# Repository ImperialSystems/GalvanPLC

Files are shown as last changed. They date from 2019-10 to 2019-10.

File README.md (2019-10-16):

# GalvanPLC
Galvan PLC es una adaptación de la plataforma Arduino al ámbito industrial, dicho de forma más clara es una imitación de los PLC. El hardware es completamente abierto y está bajo licencia GPL V2. El PCB fue diseñado en KiCAD con solo una capa y pensado para que pueda montarse tanto de forma casera como de forma profesional. Cuenta con 4 salidas digitales del tipo relay, 3 salidas analógicas de 0-5V, 2 entradas analógicas de 10V, 2 entradas analógicas de 4-20mA y 5 entradas digitales de 24V. Puede alimentarse entre 8VDC y 30VDC. Posee conexión USB y comunicación I2C. Es compatible con Soapbox Snap, OpenPLC, LDmicro y Arduino IDE, entre otros.

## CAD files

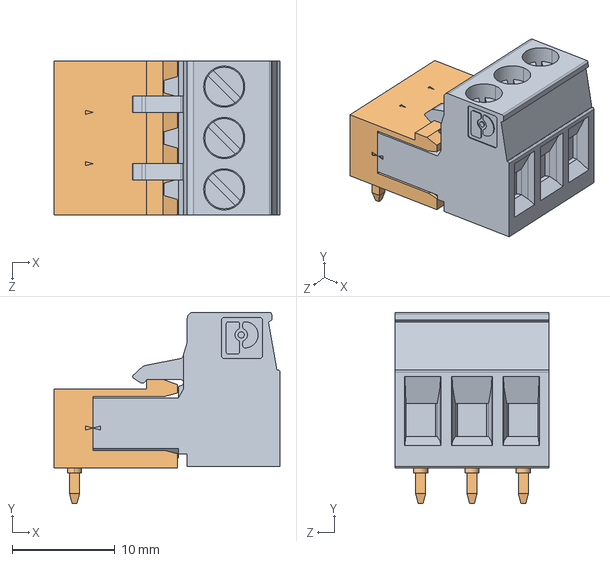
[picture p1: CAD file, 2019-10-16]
v0.0.1/PCB/STEP/MSTB 2,5_3_ST_1754465 + MSTB 2,5_ 3_G_1754452 (Phoenix Contact).STEP
22.0 x 18.6 x 15.0 mm

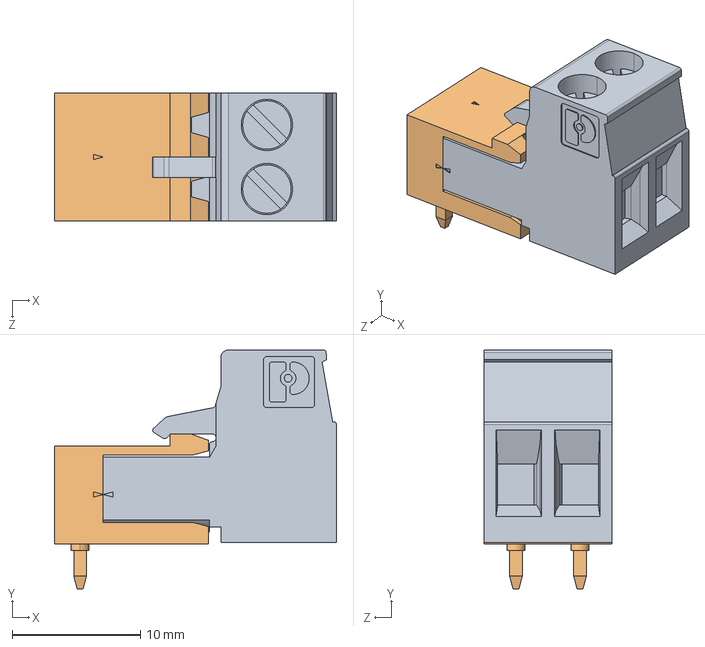
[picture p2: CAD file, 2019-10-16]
v0.0.1/PCB/STEP/MSTB 2,5_2_ST_1754449 + MSTB 2,5_ 2_G_1754436 (Phoenix Contact).STEP
22.0 x 18.6 x 10.0 mm

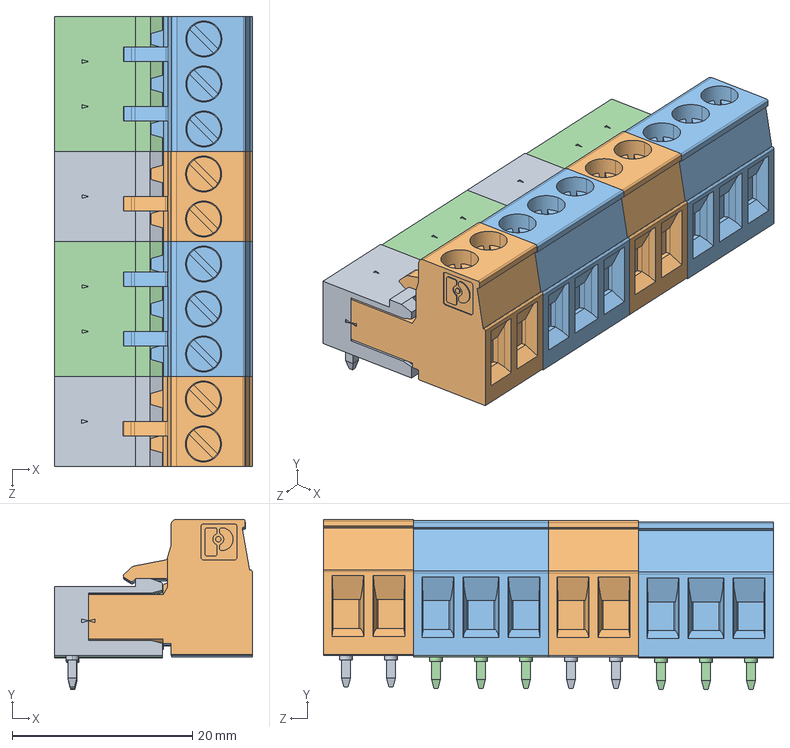
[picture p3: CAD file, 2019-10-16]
v0.0.1/PCB/STEP/MSTB 2,5_10_ST_1754465 + MSTB 2,5_ 3_G_1754452 (Phoenix Contact).STEP
22.0 x 18.9 x 50.0 mm
MSTB 2,5_2_ST_1754449 + MSTB 2,5_ 2_G_1754436 (Phoenix Contact).step
MSTB 2,5_3_ST_1754465 + MSTB 2,5_ 3_G_1754452 (Phoenix Contact).step
MSTB 2,5_2_ST_1754449 + MSTB 2,5_ 2_G_1754436 (Phoenix Contact).step.STEP
MSTB 2,5_3_ST_1754465 + MSTB 2,5_ 3_G_1754452 (Phoenix Contact).step.STEP

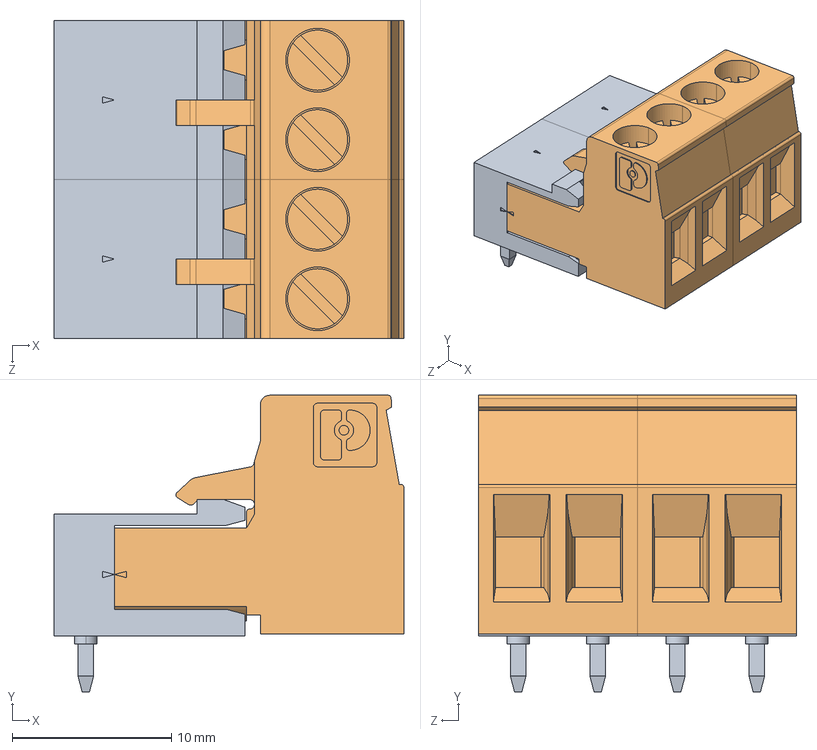
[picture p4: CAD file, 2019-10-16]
v0.0.1/PCB/STEP/MSTB 2,5_4_ST_1754465 + MSTB 2,5_ 3_G_1754452 (Phoenix Contact).STEP
22.0 x 18.6 x 20.0 mm
MSTB 2,5_2_ST_1754449 + MSTB 2,5_ 2_G_1754436 (Phoenix Contact).step x 2

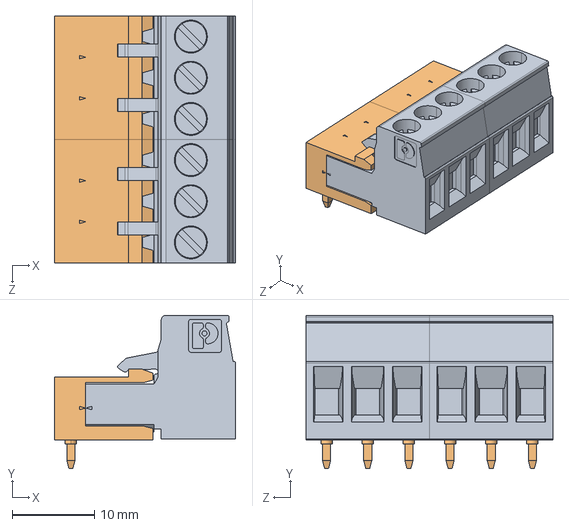
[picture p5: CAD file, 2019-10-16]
v0.0.1/PCB/STEP/MSTB 2,5_6_ST_1754465 + MSTB 2,5_ 3_G_1754452 (Phoenix Contact).STEP
22.0 x 18.6 x 30.0 mm
MSTB 2,5_3_ST_1754465 + MSTB 2,5_ 3_G_1754452 (Phoenix Contact).step x 2

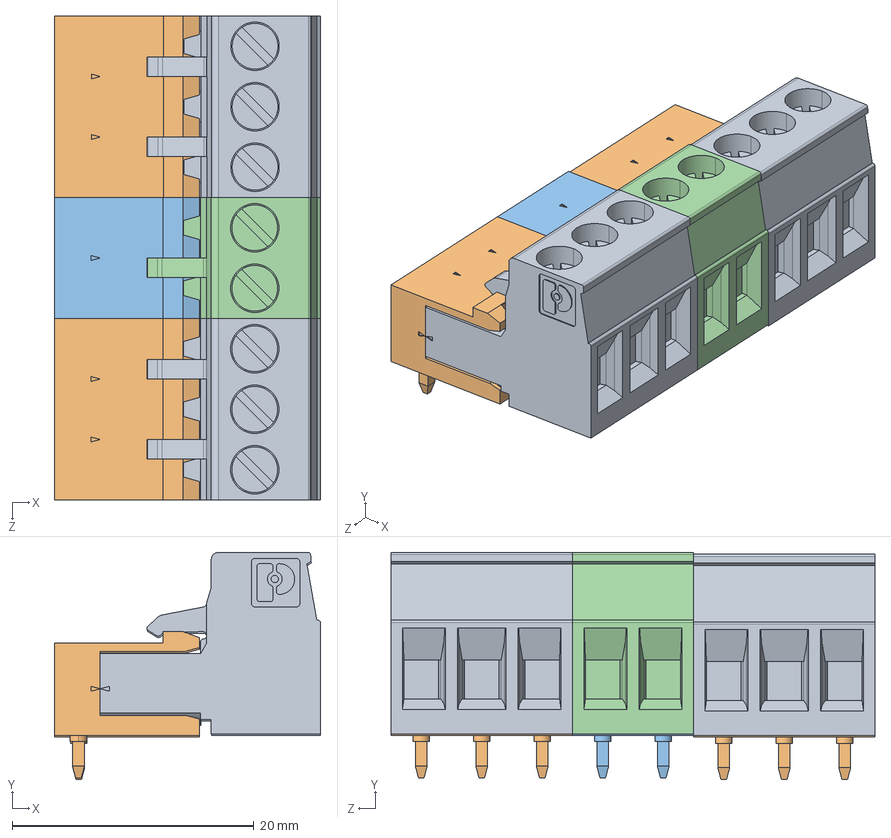
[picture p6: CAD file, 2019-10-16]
v0.0.1/PCB/STEP/MSTB 2,5_8_ST_1754465 + MSTB 2,5_ 3_G_1754452 (Phoenix Contact).STEP
22.0 x 18.8 x 40.0 mm
MSTB 2,5_3_ST_1754465 + MSTB 2,5_ 3_G_1754452 (Phoenix Contact).step
MSTB 2,5_2_ST_1754449 + MSTB 2,5_ 2_G_1754436 (Phoenix Contact).step.STEP
MSTB 2,5_3_ST_1754465 + MSTB 2,5_ 3_G_1754452 (Phoenix Contact).step.STEP

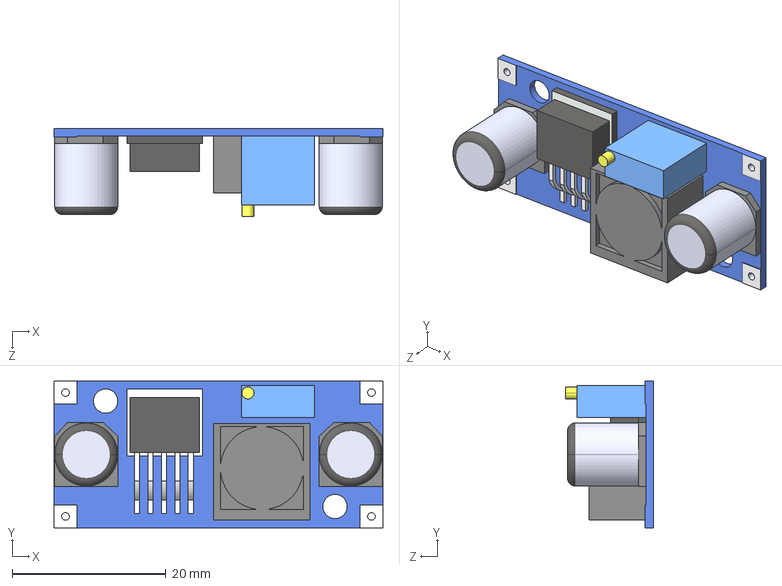
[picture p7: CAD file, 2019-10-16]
v0.0.1/PCB/STEP/stepdown voltage converter.STEP
42.9 x 19.1 x 11.5 mm

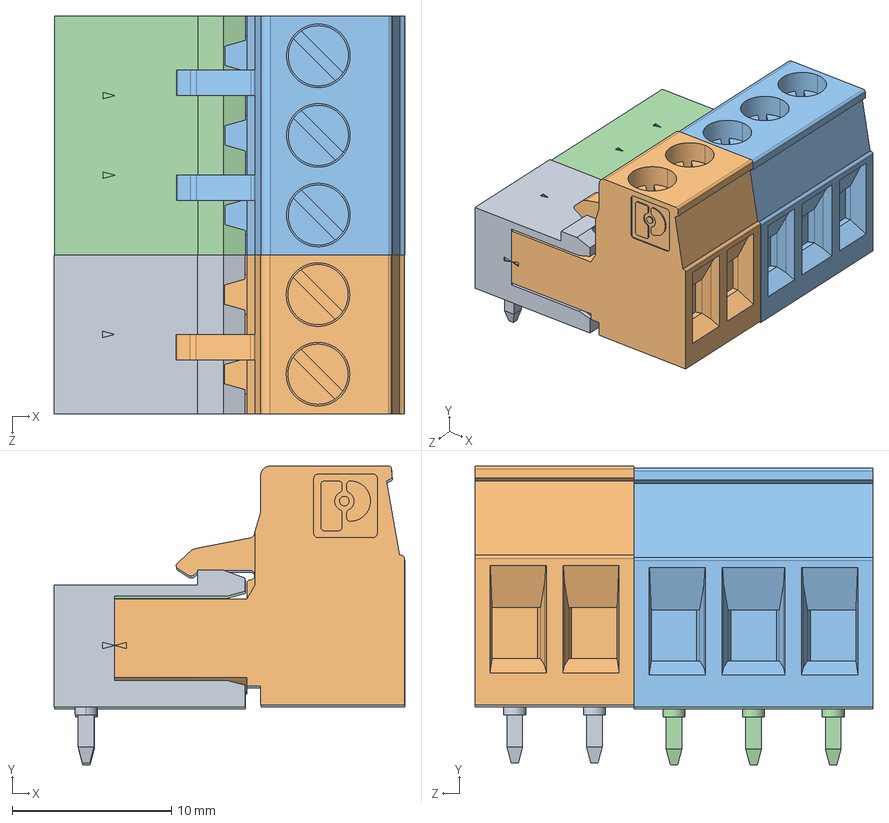
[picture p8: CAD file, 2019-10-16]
v0.0.1/PCB/STEP/MSTB 2,5_5_ST_1754449 + MSTB 2,5_ 2_G_1754436 (Phoenix Contact).STEP
22.0 x 18.8 x 25.0 mm
MSTB 2,5_2_ST_1754449 + MSTB 2,5_ 2_G_1754436 (Phoenix Contact).step
MSTB 2,5_3_ST_1754465 + MSTB 2,5_ 3_G_1754452 (Phoenix Contact).step

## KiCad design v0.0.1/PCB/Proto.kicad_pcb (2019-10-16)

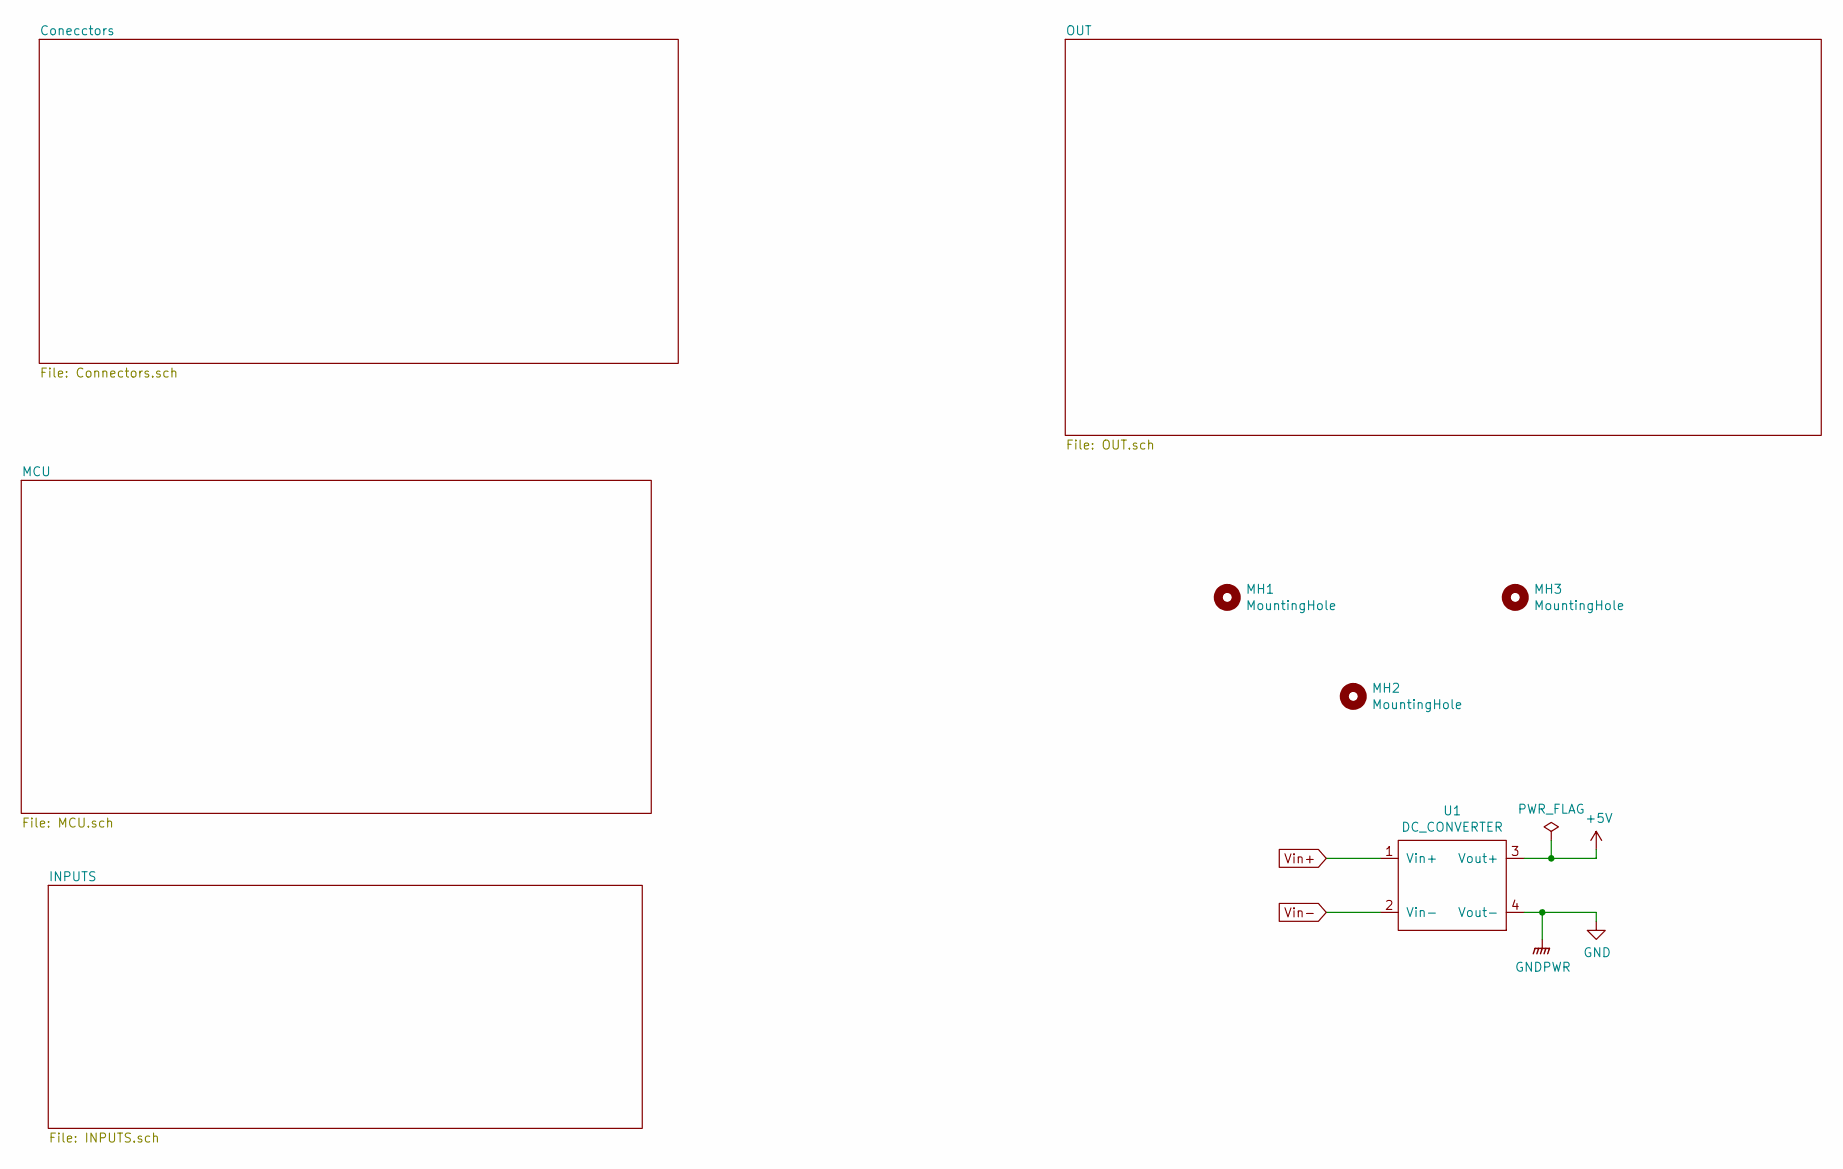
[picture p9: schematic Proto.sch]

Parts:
MH1, MH2, MH3: MountingHole; MountingHole_5mm
U1: DC_CONVERTER; Module_LM2596

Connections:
+5V: U1.3 (Vout+); also elsewhere on the board
GND: U1.4 (Vout-); also elsewhere on the board

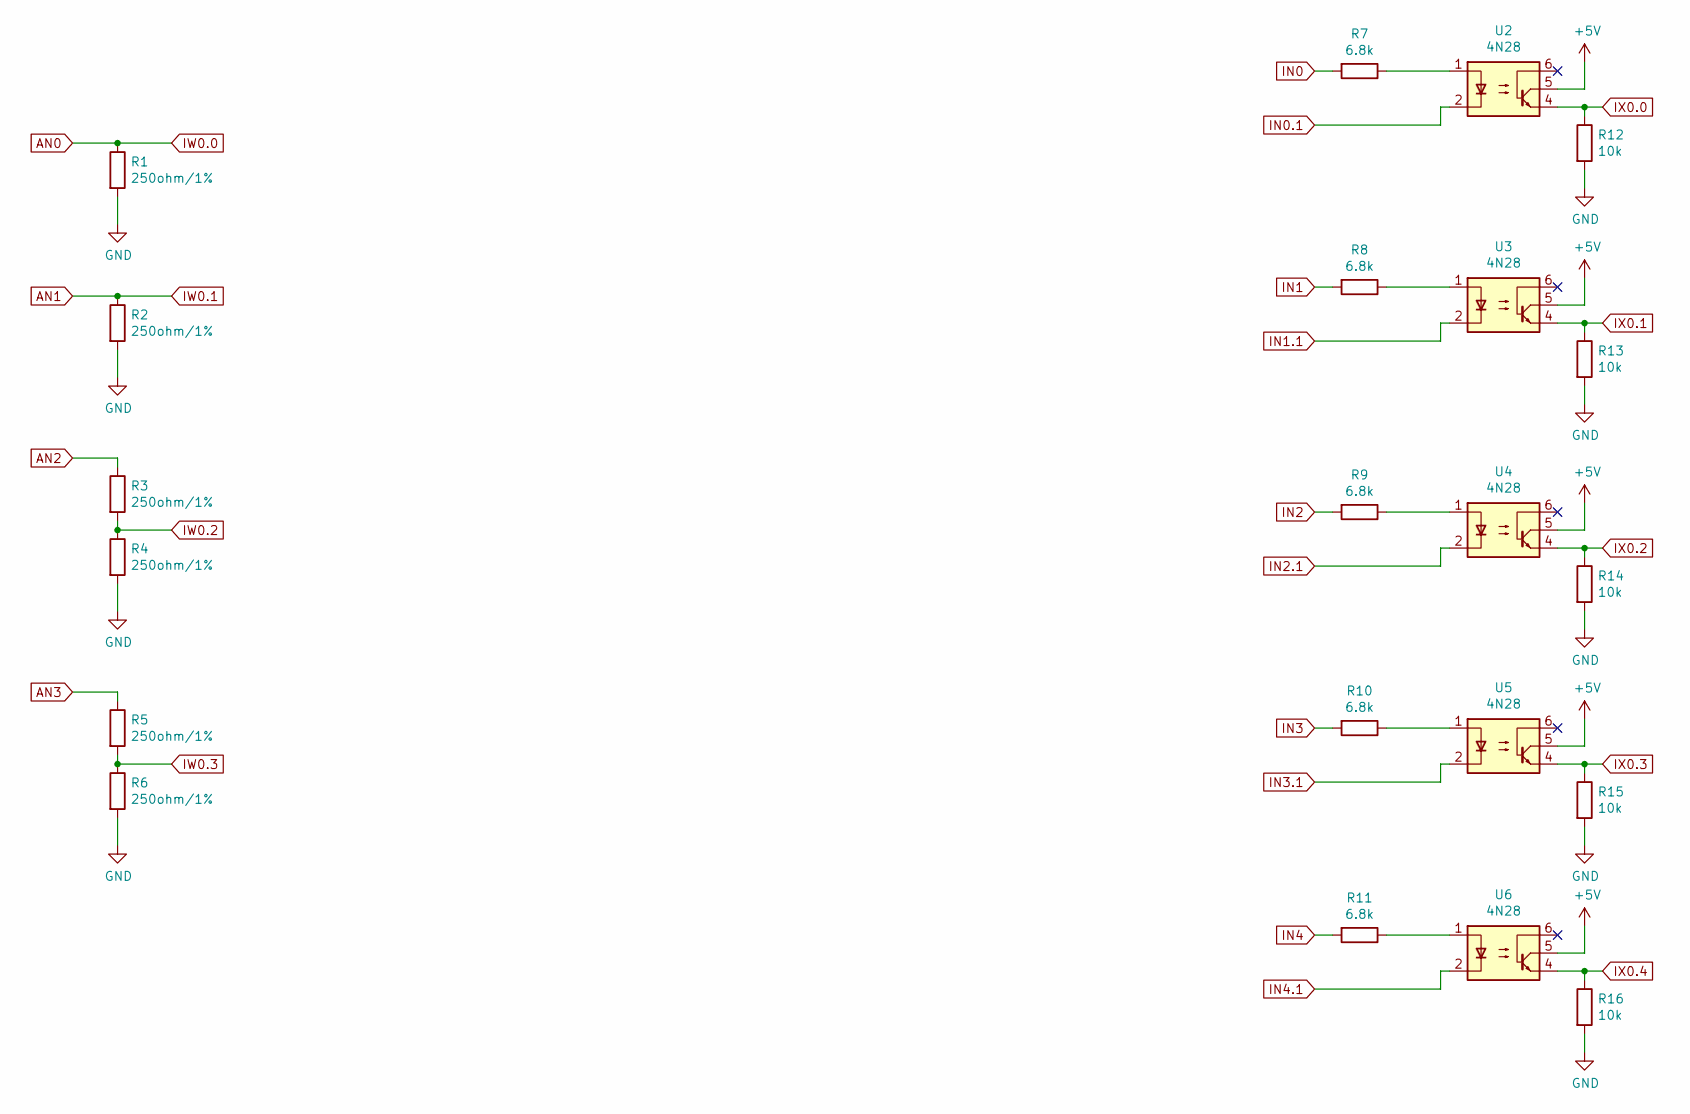
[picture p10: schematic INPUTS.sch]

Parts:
R1, R2, R4, R6: 250ohm/1%; R_Axial_DIN0207_L6.3mm_D2.5mm_P15.24mm_Horizontal
R3, R5: 250ohm/1%; R_Axial_DIN0207_L6.3mm_D2.5mm_P10.16mm_Horizontal
R7, R8, R9, R10, R11: 6.8k; R_Axial_DIN0207_L6.3mm_D2.5mm_P15.24mm_Horizontal
R12, R13, R14, R15, R16: 10k; R_Axial_DIN0207_L6.3mm_D2.5mm_P15.24mm_Horizontal
U2, U3, U4, U5, U6: 4N28; DIP-6_W7.62mm

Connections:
+5V: U2.5, U3.5, U4.5, U5.5, U6.5; also elsewhere on the board
AN0: R1.1; also elsewhere on the board
AN1: R2.1; also elsewhere on the board
AN2: R3.1; also elsewhere on the board
AN3: R5.1; also elsewhere on the board
GND: R1.2, R2.2, R4.2, R6.2, R12.2, R13.2, R14.2, R15.2, R16.2; also elsewhere on the board
IN0: R7.2; also elsewhere on the board
IN0.1: U2.2; also elsewhere on the board
IN1: R8.2; also elsewhere on the board
IN1.1: U3.2; also elsewhere on the board
IN2: R9.2; also elsewhere on the board
IN2.1: U4.2; also elsewhere on the board
IN3: R10.2; also elsewhere on the board
IN3.1: U5.2; also elsewhere on the board
IN4: R11.2; also elsewhere on the board
IN4.1: U6.2; also elsewhere on the board
IW0.2: R3.2, R4.1; also elsewhere on the board
IW0.3: R5.2, R6.1; also elsewhere on the board
IX0.0: R12.1, U2.4; also elsewhere on the board
IX0.1: R13.1, U3.4; also elsewhere on the board
IX0.2: R14.1, U4.4; also elsewhere on the board
IX0.3: R15.1, U5.4; also elsewhere on the board
IX0.4: R16.1, U6.4; also elsewhere on the board
unnamed: R7.1, U2.1
unnamed: R8.1, U3.1
unnamed: R9.1, U4.1
unnamed: R10.1, U5.1
unnamed: R11.1, U6.1

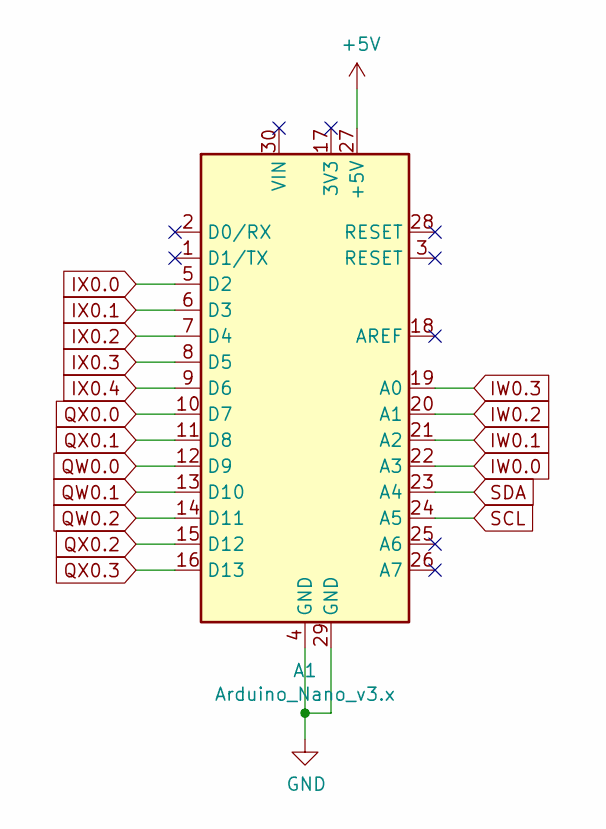
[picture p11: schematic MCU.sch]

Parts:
A1: Arduino_Nano_v3.x; Arduino_Nano

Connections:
+5V: A1.27 (+5V); also elsewhere on the board
AN0: A1.22 (A3); also elsewhere on the board
AN1: A1.21 (A2); also elsewhere on the board
GND: A1.4 (GND), A1.29 (GND); also elsewhere on the board
IW0.2: A1.20 (A1); also elsewhere on the board
IW0.3: A1.19 (A0); also elsewhere on the board
IX0.0: A1.5 (D2); also elsewhere on the board
IX0.1: A1.6 (D3); also elsewhere on the board
IX0.2: A1.7 (D4); also elsewhere on the board
IX0.3: A1.8 (D5); also elsewhere on the board
IX0.4: A1.9 (D6); also elsewhere on the board
QW0.0: A1.12 (D9); also elsewhere on the board
QW0.1: A1.13 (D10); also elsewhere on the board
QW0.2: A1.14 (D11); also elsewhere on the board
QX0.0: A1.10 (D7); also elsewhere on the board
QX0.1: A1.11 (D8); also elsewhere on the board
QX0.2: A1.15 (D12); also elsewhere on the board
QX0.3: A1.16 (D13); also elsewhere on the board
SCL: A1.24 (A5); also elsewhere on the board
SDA: A1.23 (A4); also elsewhere on the board

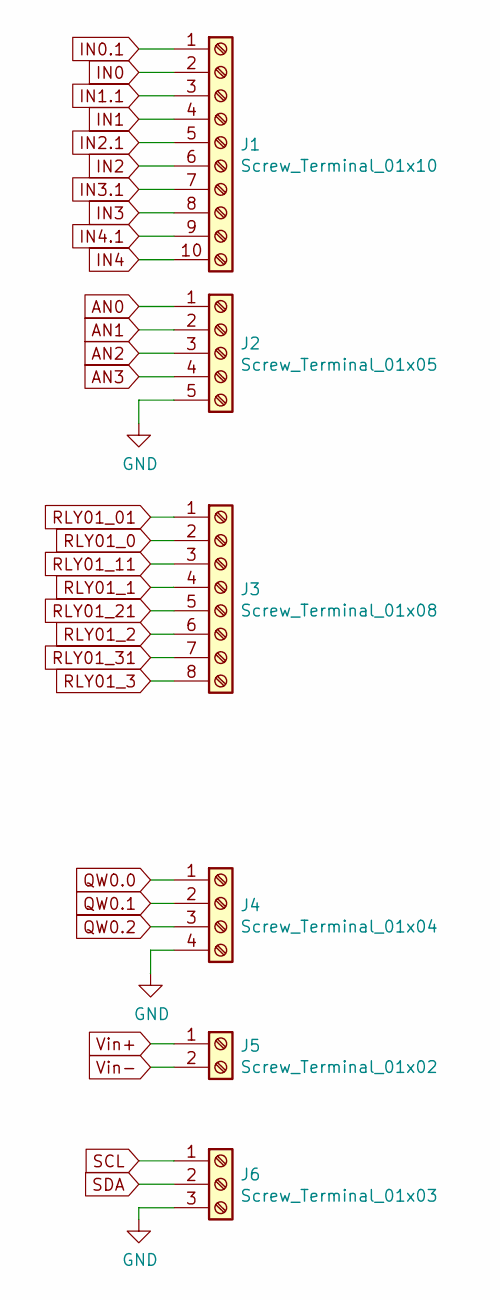
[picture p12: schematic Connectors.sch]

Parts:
J1: Screw_Terminal_01x10; TerminalBlock_Phoenix_MKDS-1,5-10-5.08_1x10_P5.08mm_Horizon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
J2: Screw_Terminal_01x05; TerminalBlock_Phoenix_MKDS-1,5-5_1x05_P5.00mm_Horizontal
J3: Screw_Terminal_01x08; TerminalBlock_Phoenix_MKDS-1,5-8_1x08_P5.00mm_Horizontal
J4: Screw_Terminal_01x04; TerminalBlock_Phoenix_MKDS-1,5-4_1x04_P5.00mm_Horizontal
J5: Screw_Terminal_01x02; TerminalBlock_Phoenix_MKDS-1,5-2_1x02_P5.00mm_Horizontal
J6: Screw_Terminal_01x03; TerminalBlock_Phoenix_MKDS-1,5-3_1x03_P5.00mm_Horizontal

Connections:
AN0: J2.1; also elsewhere on the board
AN1: J2.2; also elsewhere on the board
AN2: J2.3; also elsewhere on the board
AN3: J2.4; also elsewhere on the board
GND: J2.5, J4.4, J6.3; also elsewhere on the board
IN0: J1.2; also elsewhere on the board
IN0.1: J1.1; also elsewhere on the board
IN1: J1.4; also elsewhere on the board
IN1.1: J1.3; also elsewhere on the board
IN2: J1.6; also elsewhere on the board
IN2.1: J1.5; also elsewhere on the board
IN3: J1.8; also elsewhere on the board
IN3.1: J1.7; also elsewhere on the board
IN4: J1.10; also elsewhere on the board
IN4.1: J1.9; also elsewhere on the board
QW0.0: J4.1; also elsewhere on the board
QW0.1: J4.2; also elsewhere on the board
QW0.2: J4.3; also elsewhere on the board
RLY01_0: J3.2; also elsewhere on the board
RLY01_01: J3.1; also elsewhere on the board
RLY01_1: J3.4; also elsewhere on the board
RLY01_2: J3.6; also elsewhere on the board
RLY01_3: J3.8; also elsewhere on the board
RLY01_11: J3.3; also elsewhere on the board
RLY01_21: J3.5; also elsewhere on the board
RLY01_31: J3.7; also elsewhere on the board
SCL: J6.1; also elsewhere on the board
SDA: J6.2; also elsewhere on the board

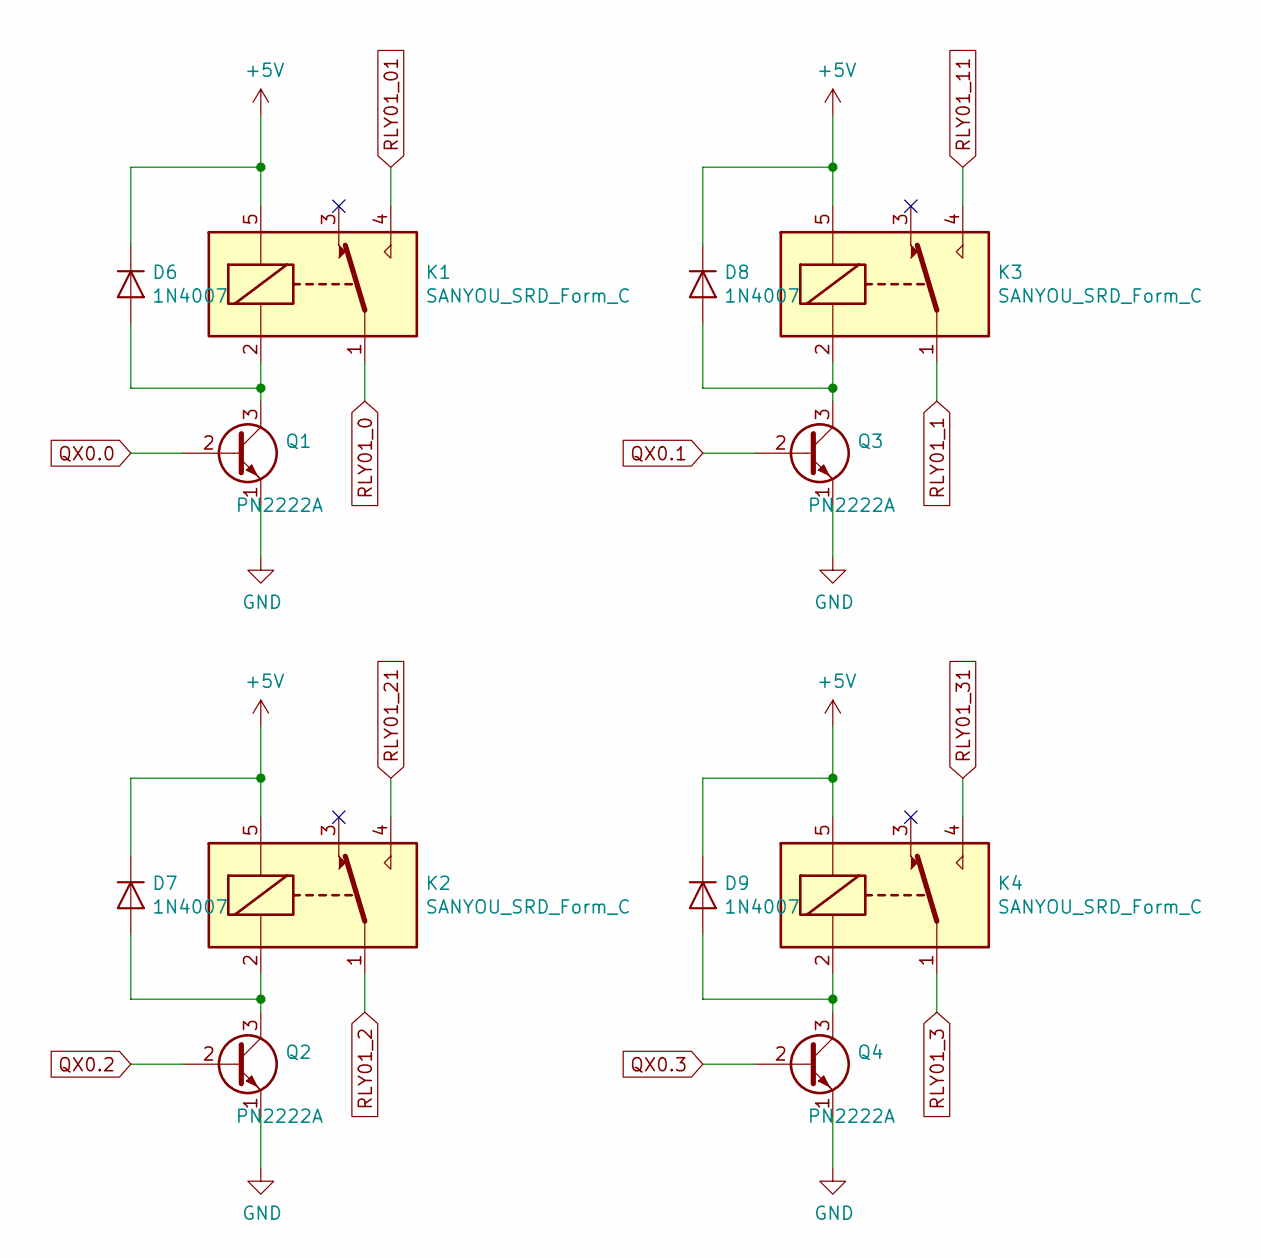
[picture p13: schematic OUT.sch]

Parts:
D6, D7, D8, D9: 1N4007; D_DO-41_SOD81_P12.70mm_Horizontal
K1, K2, K3, K4: SANYOU_SRD_Form_C; Relay_SPDT_SANYOU_SRD_Series_Form_C
Q1, Q2, Q3, Q4: PN2222A; TO-92_HandSolder

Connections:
+5V: D6.1 (K), D7.1 (K), D8.1 (K), D9.1 (K), K1.5, K2.5, K3.5, K4.5; also elsewhere on the board
GND: Q1.1 (E), Q2.1 (E), Q3.1 (E), Q4.1 (E); also elsewhere on the board
unnamed: D6.2 (A), K1.2, Q1.3 (C)
unnamed: D7.2 (A), K2.2, Q2.3 (C)
unnamed: D8.2 (A), K3.2, Q3.3 (C)
unnamed: D9.2 (A), K4.2, Q4.3 (C)
QX0.0: Q1.2 (B); also elsewhere on the board
QX0.1: Q3.2 (B); also elsewhere on the board
QX0.2: Q2.2 (B); also elsewhere on the board
QX0.3: Q4.2 (B); also elsewhere on the board
RLY01_0: K1.1; also elsewhere on the board
RLY01_01: K1.4; also elsewhere on the board
RLY01_1: K3.1; also elsewhere on the board
RLY01_2: K2.1; also elsewhere on the board
RLY01_3: K4.1; also elsewhere on the board
RLY01_11: K3.4; also elsewhere on the board
RLY01_21: K2.4; also elsewhere on the board
RLY01_31: K4.4; also elsewhere on the board

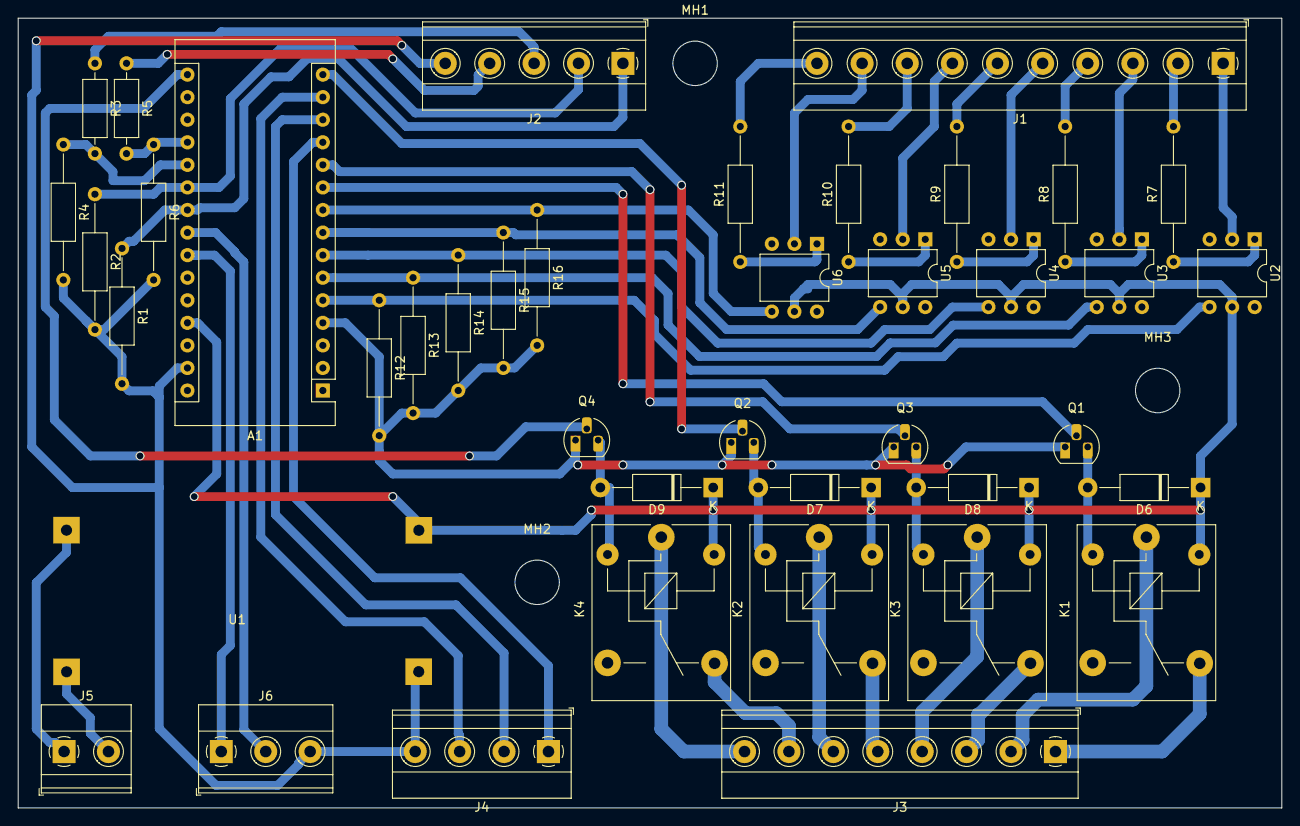
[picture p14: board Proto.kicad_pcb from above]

Board: 2 copper layers, 142.2 x 88.9 mm, 44 parts (0 on the bottom side), 49 nets.
